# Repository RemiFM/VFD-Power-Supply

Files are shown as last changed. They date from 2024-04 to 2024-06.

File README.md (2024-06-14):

# VFD Power Supply
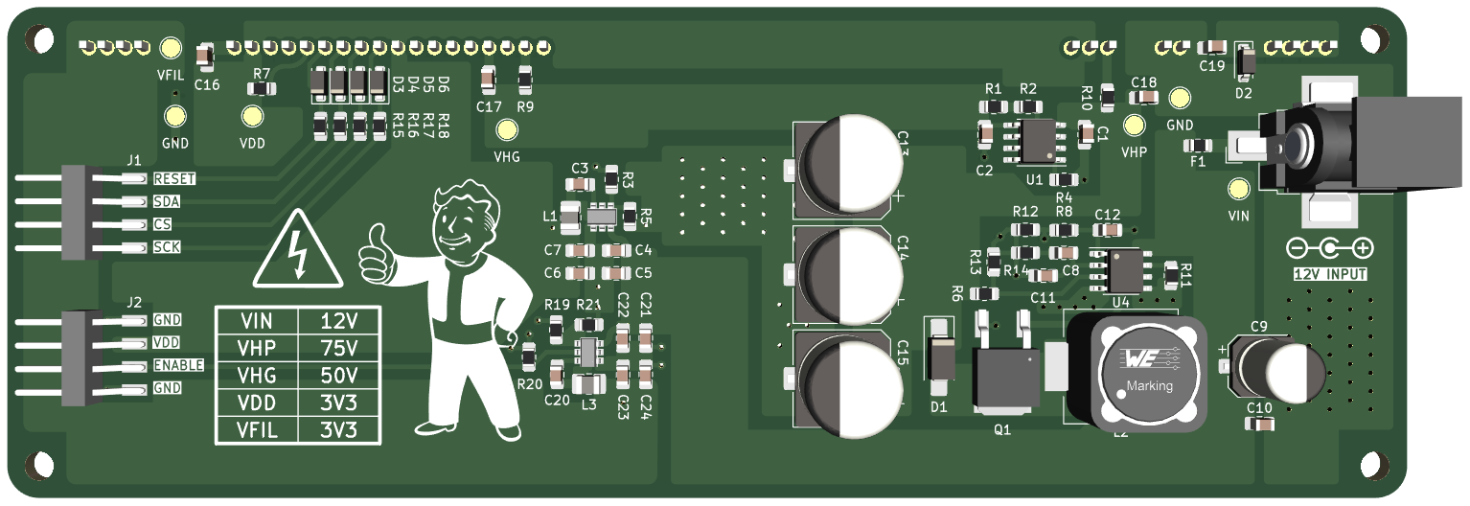
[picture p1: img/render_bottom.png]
Render Bottom


Power supply for the GP1294AI & GP1278BI (also marketed as VFD25648) vacuum fluorescent display. The supply requires a 12V input source, and outputs the necessary voltages to drive the anodes and filaments of the display. 

> [!CAUTION]
> The power supply outputs **voltages up to 75V** DC which can be hazardous. Handle with care.

## Usage
The VFD Display can be soldered to the front of the PCB. All components of the power supply are surface-mount technology (SMT) and are placed on the backside of the PCB. Only connect the display to the PCB after verifying all voltages on the power supply using the provided measuring points. The display can be controlled using any microcontroller that uses 3V3 logic (ESP32, Raspberry Pi...) using the general purpose 2.54mm male headers on the board.

## Ordering PCB
The production files necessary for manufacturing are bundled in the compressed folders [export/GP1294AI.zip](export/GP1294AI.zip) or [export/GP1278BI.zip](export/GP1278BI.zip), depending on the specific VFD display used. The gerber files are generated according to the guidelines of fabrication house JLCPCB. It is recommended to order the PCB from JLCPCB by uploading the compressed folder to their website, but other manufacturers (PCBWay, Eurocircuits...) should work as well.

## Ordering Components
A bill of materials (BOM) is available for download. The BOM contains Digi-Key part numbers, and is formatted in a way that can be uploaded to the Digi-Key website for effortless ordering.
Alternatively, the URL below leads to a public product list on Digi-Key which can be used for ordering the parts. As of June 2024, the total component cost is ~€23.

> [!TIP]
> Order all necessary components by following [this link](https://www.digikey.be/nl/mylists/list/VK1I6PIG8G). 

## Assembly
For assembly, please make use of the provided [schematic](schematic.pdf), available in pdf format.

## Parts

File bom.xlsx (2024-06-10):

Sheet: BOM
Group | Item | Designator | DigiKey | Cost | Number | Total | Remarks
Supply Voltage | Capacitor 10uF | C4 | 1276-1096-1-ND | €0.09 | 1 | €0.09 | footprint 0805
 | Capacitor 100nF | C5, C3 | 1276-6840-1-ND | €0.09 | 2 | €0.18 | footprint 0805
 | Capacitor 22uF | C6, C7 | 1276-6526-1-ND | €0.30 | 2 | €0.60 | footprint 0805
 | Resistor 31k6 | R3 | 311-31.6KCRCT-ND | €0.09 | 1 | €0.09 | footprint 0805
 | Resistor 10k | R5 | 311-10.0KCRCT-ND | €0.09 | 1 | €0.09 | footprint 0805
 | Inductor 2.2uH | L1 | 732-9690-1-ND | €0.49 | 1 | €0.49 | footprint 1008
 | Regulator AP62250 | U2 | 31-AP62250WU-7CT-ND | €0.30 | 1 | €0.30 | TSOT-26
Filament Driver | Capacitor 10uF | C21 | 1276-1096-1-ND | €0.09 | 1 | €0.09 | footprint 0805
 | Capacitor 100nF | C22, C20 | 1276-6840-1-ND | €0.09 | 2 | €0.18 | footprint 0805
 | Capacitor 22uF | C23, C24 | 1276-6526-1-ND | €0.30 | 2 | €0.60 | footprint 0805
 | Resistor 31k6 | R19 | 311-31.6KCRCT-ND | €0.09 | 1 | €0.09 | footprint 0805
 | Resistor 10k | R21, R20 | 311-10.0KCRCT-ND | €0.09 | 2 | €0.18 | footprint 0805
 | Inductor 2.2uH | L3 | 732-9690-1-ND | €0.49 | 1 | €0.49 | footprint 1008
 | Regulator AP62250 | U5 | 31-AP62250WU-7CT-ND | €0.30 | 1 | €0.30 | TSOT-26
Fused Input | Barrel Jack | J3 | CP-036AHPJCT-ND | €1.14 | 1 | €1.14
 | Barrel Plug | X | CP3-1000-ND | €1.13 | 1 | €1.13
 | 3A Fuse | F1 | MFU08053.00CT-ND | €0.56 | 1 | €0.56 | footprint 0805
Anode Driver | E-Capacitor 100uF | C9 | 732-8254-1-ND | €0.30 | 1 | €0.30
 | Capacitor 100nF | C10 | 1276-6840-1-ND | €0.09 | 1 | €0.09 | footprint 0805
 | Resistor 28k7 | R11 | 311-28.7KCRCT-ND | €0.09 | 1 | €0.09 | footprint 0805
 | Capacitor 39pF | C11 | 13-CC0805JRNPOBBN390CT-ND | €0.11 | 1 | €0.11 | HV, footprint 0805
 | Capacitor 330pF | C8 | 311-3287-1-ND | €0.13 | 1 | €0.13 | HV, footprint 0805
 | Capacitor 10pF | C12 | 311-4254-1-ND | €0.18 | 1 | €0.18 | HV, footprint 0805
 | Resistor 340k | R14 | 311-340KCRCT-ND | €0.09 | 1 | €0.09 | footprint 0805
 | Resistor 100R | R8 | 311-100CRCT-ND | €0.09 | 1 | €0.09 | footprint 0805
 | Resistor 0.1R | R12 | 311-0.1LUCT-ND | €0.39 | 1 | €0.39 | footprint 0805
 | Resistor 590k | R6 | 311-590KCRCT-ND | €0.09 | 1 | €0.09 | footprint 0805
 | Resistor 10k | R13 | 311-10.0KCRCT-ND | €0.09 | 1 | €0.09 | footprint 0805
 | Regulator LM3478 | U4 | 296-38111-1-ND | €2.41 | 1 | €2.41
 | Inductor 220uH | L2 | 732-1696-1-ND | €2.36 | 1 | €2.36
 | Diode SK220A | D1 | 1655-SK220ACT-ND | €0.41 | 1 | €0.41
 | Mosfet NCH | Q1 | 497-8774-1-ND | €2.69 | 1 | €2.69
 | E-Capacitor 47uF | C13, C14, C15 | 399-14797-1-ND | €0.68 | 3 | €2.04 | HV
Grid Driver | Capacitor 1uF | C1, C2 | 1276-1066-1-ND | €0.09 | 2 | €0.18 | footprint 0805
 | Resistor 220k | R4 | 311-220KARCT-ND | €0.09 | 1 | €0.09 | footprint 0806
 | Resistor 5K6 | R1 | 311-5.6KARCT-ND | €0.09 | 1 | €0.09 | footprint 0807
 | Resistor 56R | R2 | 311-56ARCT-ND | €0.09 | 1 | €0.09 | footprint 0808
 | Regulator | U1 | LR12LG-GCT-ND | €1.54 | 1 | €1.54
Connector | Male connector | J1, J2 | 952-3265-ND | €0.61 | 2 | €1.22
VFD Display | Resistor 200R | R15, R16, R17, R18 | 311-200CRCT-ND | €0.09 | 4 | €0.36
 | Resistor 100k | R7 | 311-100KCRCT-ND | €0.09 | 1 | €0.09
 | Resistor 10R | R9, R10 | 13-AC0805FR-7W10RLCT-ND | €0.09 | 2 | €0.18 | HV
 | Capacitor 100nF | C16, C19, C17, C18 | 1276-6840-1-ND | €0.09 | 4 | €0.36
 | Diode BZT52B3V3 | D3, D4, D5, D6 | BZT52B3V3RHGCT-ND | €0.19 | 4 | €0.76
 | Zener Diode | D2 | MMSZ5222BT1GOSCT-ND | €0.21 | 1 | €0.21
 |  |  |  |  |  | €23.33

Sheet: abridged
Item | Designator | DigiKey | Cost | Number | Total
Capacitor 10uF | C4 | 1276-1096-1-ND | 0.09 | 1 | 0.09
Capacitor 100nF | C5, C3 | 1276-6840-1-ND | 0.09 | 2 | 0.18
Capacitor 22uF | C6, C7 | 1276-6526-1-ND | 0.3 | 2 | 0.6
Resistor 31k6 | R3 | 311-31.6KCRCT-ND | 0.09 | 1 | 0.09
Resistor 10k | R5 | 311-10.0KCRCT-ND | 0.09 | 1 | 0.09
Inductor 2.2uH | L1 | 732-9690-1-ND | 0.49 | 1 | 0.49
Regulator AP62250 | U2 | 31-AP62250WU-7CT-ND | 0.3 | 1 | 0.3
Capacitor 10uF | C21 | 1276-1096-1-ND | 0.09 | 1 | 0.09
Capacitor 100nF | C22, C20 | 1276-6840-1-ND | 0.09 | 2 | 0.18
Capacitor 22uF | C23, C24 | 1276-6526-1-ND | 0.3 | 2 | 0.6
Resistor 31k6 | R19 | 311-31.6KCRCT-ND | 0.09 | 1 | 0.09
Resistor 10k | R21, R20 | 311-10.0KCRCT-ND | 0.09 | 2 | 0.18
Inductor 2.2uH | L3 | 732-9690-1-ND | 0.49 | 1 | 0.49
Regulator AP62250 | U5 | 31-AP62250WU-7CT-ND | 0.3 | 1 | 0.3
Barrel Jack | J3 | CP-036AHPJCT-ND | 1.14 | 1 | 1.14
Barrel Plug | X | CP3-1000-ND | 1.13 | 1 | 1.13
3A Fuse | F1 | MFU08053.00CT-ND | 0.56 | 1 | 0.56
E-Capacitor 100uF | C9 | 732-8254-1-ND | 0.3 | 1 | 0.3
Capacitor 100nF | C10 | 1276-6840-1-ND | 0.09 | 1 | 0.09
Resistor 28k7 | R11 | 311-28.7KCRCT-ND | 0.09 | 1 | 0.09
Capacitor 39pF | C11 | 13-CC0805JRNPOBBN390CT-ND | 0.11 | 1 | 0.11
Capacitor 330pF | C8 | 311-3287-1-ND | 0.13 | 1 | 0.13
Capacitor 10pF | C12 | 311-4254-1-ND | 0.18 | 1 | 0.18
Resistor 340k | R14 | 311-340KCRCT-ND | 0.09 | 1 | 0.09
Resistor 100R | R8 | 311-100CRCT-ND | 0.09 | 1 | 0.09
Resistor 0.1R | R12 | 311-0.1LUCT-ND | 0.39 | 1 | 0.39
Resistor 590k | R6 | 311-590KCRCT-ND | 0.09 | 1 | 0.09
Resistor 10k | R13 | 311-10.0KCRCT-ND | 0.09 | 1 | 0.09
Regulator LM3478 | U4 | 296-38111-1-ND | 2.41 | 1 | 2.41
Inductor 220uH | L2 | 732-1696-1-ND | 2.36 | 1 | 2.36
Diode SK220A | D1 | 1655-SK220ACT-ND | 0.41 | 1 | 0.41
Mosfet NCH | Q1 | 497-8774-1-ND | 2.69 | 1 | 2.69
E-Capacitor 47uF | C13, C14, C15 | 399-14797-1-ND | 0.68 | 3 | 2.04
Capacitor 1uF | C1, C2 | 1276-1066-1-ND | 0.09 | 2 | 0.18
Resistor 220k | R4 | 311-220KARCT-ND | 0.09 | 1 | 0.09
Resistor 5K6 | R1 | 311-5.6KARCT-ND | 0.09 | 1 | 0.09
Resistor 56R | R2 | 311-56ARCT-ND | 0.09 | 1 | 0.09
Regulator | U1 | LR12LG-GCT-ND | 1.54 | 1 | 1.54
Male connector | J1, J2 | 952-3265-ND | 0.61 | 2 | 1.22
Resistor 200R | R15, R16, R17, R18 | 311-200CRCT-ND | 0.09 | 4 | 0.36
Resistor 100k | R7 | 311-100KCRCT-ND | 0.09 | 1 | 0.09
Resistor 10R | R9, R10 | 13-AC0805FR-7W10RLCT-ND | 0.09 | 2 | 0.18
Capacitor 100nF | C16, C19, C17, C18 | 1276-6840-1-ND | 0.09 | 4 | 0.36
Diode BZT52B3V3 | D3, D4, D5, D6 | BZT52B3V3RHGCT-ND | 0.19 | 4 | 0.76
Zener Diode | D2 | MMSZ5222BT1GOSCT-ND | 0.21 | 1 | 0.21

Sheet: obsolete
Item | Designator | Digikey | Cost | Quantity | Total
Capacitor 10uF | C26, C14 |  |  | 2 | €0.00
Capacitor 100n | C13, C28, C3, C24, C27 |  |  | 5 | €0.00
Capacitor 1uF | C12 |  |  | 1 | €0.00
Resistor 10k | R11 |  |  | 1 | €0.00
Resistor 100k | R10, R17 |  |  | 2 | €0.00
Inductor 2.2uH | L2 | SRR1260-2R2YCT-ND | €1.09 | 1 | €1.09
Capacitor 15pF | C29 |  |  | 1 | €0.00
Resistor 22k1 | R25 |  |  | 1 | €0.00
Resistor 73k2 | R12 |  |  | 1 | €0.00
Capacitor 47uF | C30 |  |  | 1 | €0.00
Regulator IC | U6 | 296-40815-1-ND | €1.82 | 1 | €1.82
Capacitor 100 uF | C4 | 732-8254-1-ND | €0.30 | 1 | €0.30
Resistor 28k7 | R2 |  |  |  | €0.00
Capacitor 39pF | C1 |  |  |  | €0.00
Resistor 340k | R1 |  |  |  | €0.00
Capacitor 330 pF | C2 |  |  |  | €0.00
Regulator IC | U1 | 296-38111-1-ND | €2.41 | 1 | €2.41
Inductor 220uH | L1 | 732-1696-1-ND | €2.37 | 1 | €2.37
Mosfet NCH | Q1 | 497-8774-1-ND | €2.69 | 1 | €2.69
Capacitor HV? 10 pF | C5 |  |  |  | €0.00
Resistor HV 100R | R3 |  |  |  | €0.00
Resistor HV 100m | R4 |  |  |  | €0.00
Schottky diode | D1 | 1655-SK220ACT-ND | €0.41 | 1 | €0.41
Capacitor 47uF | C6, C7, C11 | 732-865060857005CT-ND | €1.02 | 3 | €3.06
Resistor 590k HV | R5 |  |  |  | €0.00
Resistor 10k HV | R6 |  |  |  | €0.00
Resistor 68R | R13 |  |  |  | €0.00
SSR IC | U3 | 264-TLP170AM(TPLECT-ND | €1.18 | 1 | €1.18
Barrel jack | J4 | CP-036AHPJCT-ND | €1.14 | 1 | €1.14
Fuse 3A | F1 | MFU08053.00CT-ND | €0.46 | 1 | €0.46
Connector | J1, J2 | 455-S4B-PH-SM4-TBCT-ND | €0.72 | 2 | €1.44
Capacitor 1uF HV | C9, C10 |  |  | 2 | €0.00
Regulator IC | U2 | LR12LG-GCT-ND | €1.54 | 1 | €1.54
Resistor 220k HV | R7 |  |  | 1 | €0.00
Resistor 56R HV | R9 |  |  | 1 | €0.00
Resistor 5K6 HV | R8 |  |  | 1 | €0.00
Resistor 200R | R21 X 4 |  |  | 4 | €0.00
Zener diode | D4, D5, D6, D7 | BZT52B3V3RHGCT-ND | €0.19 | 4 | €0.76
Resistor 10R HV | R19, R20 |  |  | 2 | €0.00
Capacitor 100nF HV | C25, C8 |  |  | 2 | €0.00
Zener diode | D8 | MMSZ5222BT1GOSCT-ND | €0.21 | 1 | €0.21
 |  |  |  |  | €20.88

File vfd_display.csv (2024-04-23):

Source: | C:\Users\remi.decoster\OneDrive - Flanders Make vzw\Documents\GitHub\PCBs\VFD Display\vfd_display\vfd_display.kicad_sch
Date: | 22/04/2024 00:50:16
Tool: | Eeschema 7.0.7
Generator: | C:\Program Files\KiCad\6.0\bin\scripting\plugins/bom_csv_grouped_by_value.py
Component Count: | 60
Individual Components:
Item | Qty | Reference(s) | Value | LibPart | Footprint | Datasheet | Digi-Key | DigiKey
 |  | C1 | 39pF | Device:C | Capacitor_SMD:C_0805_2012Metric_Pad1.18x1.45mm_HandSolder | ~
 |  | C2 | 330pF | Device:C | Capacitor_SMD:C_0805_2012Metric_Pad1.18x1.45mm_HandSolder | ~
 |  | C3 | 100nF | Device:C | Capacitor_SMD:C_0805_2012Metric_Pad1.18x1.45mm_HandSolder | ~
 |  | C4 | 100uF | Device:C_Polarized_US | Capacitor_SMD:CP_Elec_6.3x7.7 | ~ | 732-8254-1-ND
 |  | C5 | 10pF | Device:C | Capacitor_SMD:C_0805_2012Metric_Pad1.18x1.45mm_HandSolder | ~
 |  | C6 | 47uF | Device:C_Polarized_US | Capacitor_SMD:CP_Elec_10x10.5 | ~ | 732-865060857005CT-ND
 |  | C7 | 47uF | Device:C_Polarized_US | Capacitor_SMD:CP_Elec_10x10.5 | ~ | 732-865060857005CT-ND
 |  | C8 | 100nF | Device:C | Capacitor_SMD:C_0805_2012Metric_Pad1.18x1.45mm_HandSolder | ~
 |  | C9 | 1uF | Device:C | Capacitor_SMD:C_0805_2012Metric_Pad1.18x1.45mm_HandSolder | ~
 |  | C10 | 1uF | Device:C | Capacitor_SMD:C_0805_2012Metric_Pad1.18x1.45mm_HandSolder | ~
 |  | C11 | 47uF | Device:C_Polarized_US | Capacitor_SMD:CP_Elec_10x10.5 | ~ | 732-865060857005CT-ND
 |  | C12 | 1uF | Device:C | Capacitor_SMD:C_0805_2012Metric_Pad1.18x1.45mm_HandSolder | ~
 |  | C13 | 100nF | Device:C | Capacitor_SMD:C_0805_2012Metric_Pad1.18x1.45mm_HandSolder | ~
 |  | C14 | 10uF | Device:C | Capacitor_SMD:C_0805_2012Metric_Pad1.18x1.45mm_HandSolder | ~
 |  | C24 | 100nF | Device:C | Capacitor_SMD:C_0805_2012Metric_Pad1.18x1.45mm_HandSolder | ~
 |  | C25 | 100nF | Device:C | Capacitor_SMD:C_0805_2012Metric_Pad1.18x1.45mm_HandSolder | ~
 |  | C26 | 10uF | Device:C | Capacitor_SMD:C_0805_2012Metric_Pad1.18x1.45mm_HandSolder | ~
 |  | C27 | 100nF | Device:C | Capacitor_SMD:C_0805_2012Metric_Pad1.18x1.45mm_HandSolder | ~
 |  | C28 | 100nF | Device:C | Capacitor_SMD:C_0805_2012Metric_Pad1.18x1.45mm_HandSolder | ~
 |  | C29 | 15pF | Device:C | Capacitor_SMD:C_0805_2012Metric_Pad1.18x1.45mm_HandSolder | ~
 |  | C30 | 47uF | Device:C | Capacitor_SMD:C_0805_2012Metric_Pad1.18x1.45mm_HandSolder | ~
 |  | D1 | SK220A | Device:D_Schottky | Diode_SMD:D_SMA_Handsoldering | ~ | 1655-SK220ACT-ND
 |  | D4 | BZT52B3V3 | Device:D_Zener | Diode_SMD:D_SOD-123F | ~
 |  | D5 | BZT52B3V3 | Device:D_Zener | Diode_SMD:D_SOD-123F | ~
 |  | D6 | BZT52B3V3 | Device:D_Zener | Diode_SMD:D_SOD-123F | ~
 |  | D7 | BZT52B3V3 | Device:D_Zener | Diode_SMD:D_SOD-123F | ~
 |  | D8 | MMSZ5222BT1G | Device:D_Zener | Diode_SMD:D_SOD-123 | ~ | MMSZ5222BT1GOSCT-ND
 |  | F1 | MFU0805FF03000P100 | Device:Fuse | Fuse:Fuse_0805_2012Metric_Pad1.15x1.40mm_HandSolder | ~
 |  | J1 | Conn_01x04 | Connector_Generic:Conn_01x04 | Connector_JST:JST_PH_S4B-PH-SM4-TB_1x04-1MP_P2.00mm_Horizontal | ~ | 455-S4B-PH-SM4-TBCT-ND
 |  | J2 | Conn_01x04 | Connector_Generic:Conn_01x04 | Connector_JST:JST_PH_S4B-PH-SM4-TB_1x04-1MP_P2.00mm_Horizontal | ~ | 455-S4B-PH-SM4-TBCT-ND
 |  | J4 | PJ-036AH-SMT-TR | Connector:Barrel_Jack_Switch | Connector_BarrelJack:BarrelJack_CUI_PJ-036AH-SMT_Horizontal | ~
 |  | L1 | 220uH | Device:L | Inductor_SMD:L_Wuerth_WE-PD-Typ-LS_Handsoldering | ~ |  | 732-1696-1-ND
 |  | L2 | 2.2uH | Device:L | Inductor_SMD:L_Bourns_SRR1260 | ~ |  | SRR1260-2R2YCT-ND
 |  | Q1 | STD16N65M5 | Device:Q_NMOS_GDS | Remi_Footprints:STD16N65M5 | ~ | ?
 |  | R1 | 340k | Device:R_US | Resistor_SMD:R_0805_2012Metric_Pad1.20x1.40mm_HandSolder | ~
 |  | R2 | 28k7 | Device:R_US | Resistor_SMD:R_0805_2012Metric_Pad1.20x1.40mm_HandSolder | ~
 |  | R3 | 100R | Device:R_US | Resistor_SMD:R_0805_2012Metric_Pad1.20x1.40mm_HandSolder | ~
 |  | R4 | 100m | Device:R_US | Resistor_SMD:R_0805_2012Metric_Pad1.20x1.40mm_HandSolder | ~
 |  | R5 | 590k | Device:R_US | Resistor_SMD:R_0805_2012Metric_Pad1.20x1.40mm_HandSolder | ~
 |  | R6 | 10k | Device:R_US | Resistor_SMD:R_0805_2012Metric_Pad1.20x1.40mm_HandSolder | ~
 |  | R7 | 220k | Device:R_US | Resistor_SMD:R_0805_2012Metric_Pad1.20x1.40mm_HandSolder | ~
 |  | R8 | 5K6 | Device:R_US | Resistor_SMD:R_0805_2012Metric_Pad1.20x1.40mm_HandSolder | ~
 |  | R9 | 56R | Device:R_US | Resistor_SMD:R_0805_2012Metric_Pad1.20x1.40mm_HandSolder | ~
 |  | R10 | 100k | Device:R_US | Resistor_SMD:R_0805_2012Metric_Pad1.20x1.40mm_HandSolder | ~
 |  | R11 | 10k | Device:R_US | Resistor_SMD:R_0805_2012Metric_Pad1.20x1.40mm_HandSolder | ~
 |  | R12 | 73k2 | Device:R_US | Resistor_SMD:R_0805_2012Metric_Pad1.20x1.40mm_HandSolder | ~
 |  | R13 | 68R | Device:R_US | Resistor_SMD:R_0805_2012Metric_Pad1.20x1.40mm_HandSolder | ~
 |  | R17 | 100k | Device:R_US | Resistor_SMD:R_0805_2012Metric_Pad1.20x1.40mm_HandSolder | ~
 |  | R19 | 10R | Device:R_US | Resistor_SMD:R_0805_2012Metric_Pad1.20x1.40mm_HandSolder | ~
 |  | R20 | 10R | Device:R_US | Resistor_SMD:R_0805_2012Metric_Pad1.20x1.40mm_HandSolder | ~
 |  | R21 | 4 X 200R | Device:R_US | Resistor_SMD:R_0805_2012Metric_Pad1.20x1.40mm_HandSolder | ~
 |  | R22 | 200R | Device:R_US | Resistor_SMD:R_0805_2012Metric_Pad1.20x1.40mm_HandSolder | ~
 |  | R23 | 200R | Device:R_US | Resistor_SMD:R_0805_2012Metric_Pad1.20x1.40mm_HandSolder | ~
 |  | R24 | 200R | Device:R_US | Resistor_SMD:R_0805_2012Metric_Pad1.20x1.40mm_HandSolder | ~
 |  | R25 | 22k1 | Device:R_US | Resistor_SMD:R_0805_2012Metric_Pad1.20x1.40mm_HandSolder | ~
 |  | U1 | LM3478 | Regulator_Controller:LM3478MA | Package_SO:SOIC-8_3.9x4.9mm_P1.27mm | https://www.ti.com/lit/gpn/lm3478 | 296-38111-1-ND
 |  | U2 | LR12LG-G | Remi_Symbols:LR12 | Package_SO:SOIC-8_3.9x4.9mm_P1.27mm |  | LR12LG-GCT-ND
 |  | U3 | TLP170AM | Remi_Symbols:TLP170AM | Remi_Footprints:Toshiba-11-4M1S |  | 264-TLP170AM(TPLECT-ND
 |  | U5 | GP1294AI | Remi_Symbols:GP1294AI | Remi_Footprints:VFD_GP1294AI
 |  | U6 | TPS56628 | Remi_Symbols:TPS56628 | Package_SO:SOIC-8_3.9x4.9mm_P1.27mm
Collated Components:
Item | Qty | Reference(s) | Value | LibPart | Footprint | Datasheet | Digi-Key | DigiKey
1 | 1 | C1 | 39pF | Device:C | Capacitor_SMD:C_0805_2012Metric_Pad1.18x1.45mm_HandSolder | ~
2 | 1 | C2 | 330pF | Device:C | Capacitor_SMD:C_0805_2012Metric_Pad1.18x1.45mm_HandSolder | ~
3 | 7 | C3, C8, C13, C24, C25, C27, C28 | 100nF | Device:C | Capacitor_SMD:C_0805_2012Metric_Pad1.18x1.45mm_HandSolder | ~
4 | 1 | C4 | 100uF | Device:C_Polarized_US | Capacitor_SMD:CP_Elec_6.3x7.7 | ~ | 732-8254-1-ND
5 | 1 | C5 | 10pF | Device:C | Capacitor_SMD:C_0805_2012Metric_Pad1.18x1.45mm_HandSolder | ~
6 | 3 | C6, C7, C11 | 47uF | Device:C_Polarized_US | Capacitor_SMD:CP_Elec_10x10.5 | ~ | 732-865060857005CT-ND
7 | 3 | C9, C10, C12 | 1uF | Device:C | Capacitor_SMD:C_0805_2012Metric_Pad1.18x1.45mm_HandSolder | ~
8 | 2 | C14, C26 | 10uF | Device:C | Capacitor_SMD:C_0805_2012Metric_Pad1.18x1.45mm_HandSolder | ~
9 | 1 | C29 | 15pF | Device:C | Capacitor_SMD:C_0805_2012Metric_Pad1.18x1.45mm_HandSolder | ~
10 | 1 | C30 | 47uF | Device:C | Capacitor_SMD:C_0805_2012Metric_Pad1.18x1.45mm_HandSolder | ~
11 | 1 | D1 | SK220A | Device:D_Schottky | Diode_SMD:D_SMA_Handsoldering | ~ | 1655-SK220ACT-ND
12 | 4 | D4, D5, D6, D7 | BZT52B3V3 | Device:D_Zener | Diode_SMD:D_SOD-123F | ~
13 | 1 | D8 | MMSZ5222BT1G | Device:D_Zener | Diode_SMD:D_SOD-123 | ~ | MMSZ5222BT1GOSCT-ND
14 | 1 | F1 | MFU0805FF03000P100 | Device:Fuse | Fuse:Fuse_0805_2012Metric_Pad1.15x1.40mm_HandSolder | ~
15 | 2 | J1, J2 | Conn_01x04 | Connector_Generic:Conn_01x04 | Connector_JST:JST_PH_S4B-PH-SM4-TB_1x04-1MP_P2.00mm_Horizontal | ~ | 455-S4B-PH-SM4-TBCT-ND
16 | 1 | J4 | PJ-036AH-SMT-TR | Connector:Barrel_Jack_Switch | Connector_BarrelJack:BarrelJack_CUI_PJ-036AH-SMT_Horizontal | ~
17 | 1 | L1 | 220uH | Device:L | Inductor_SMD:L_Wuerth_WE-PD-Typ-LS_Handsoldering | ~ |  | 732-1696-1-ND
18 | 1 | L2 | 2.2uH | Device:L | Inductor_SMD:L_Bourns_SRR1260 | ~ |  | SRR1260-2R2YCT-ND
19 | 1 | Q1 | STD16N65M5 | Device:Q_NMOS_GDS | Remi_Footprints:STD16N65M5 | ~ | ?
20 | 1 | R1 | 340k | Device:R_US | Resistor_SMD:R_0805_2012Metric_Pad1.20x1.40mm_HandSolder | ~
21 | 1 | R2 | 28k7 | Device:R_US | Resistor_SMD:R_0805_2012Metric_Pad1.20x1.40mm_HandSolder | ~
22 | 1 | R3 | 100R | Device:R_US | Resistor_SMD:R_0805_2012Metric_Pad1.20x1.40mm_HandSolder | ~
23 | 1 | R4 | 100m | Device:R_US | Resistor_SMD:R_0805_2012Metric_Pad1.20x1.40mm_HandSolder | ~
24 | 1 | R5 | 590k | Device:R_US | Resistor_SMD:R_0805_2012Metric_Pad1.20x1.40mm_HandSolder | ~
25 | 2 | R6, R11 | 10k | Device:R_US | Resistor_SMD:R_0805_2012Metric_Pad1.20x1.40mm_HandSolder | ~
26 | 1 | R7 | 220k | Device:R_US | Resistor_SMD:R_0805_2012Metric_Pad1.20x1.40mm_HandSolder | ~
27 | 1 | R8 | 5K6 | Device:R_US | Resistor_SMD:R_0805_2012Metric_Pad1.20x1.40mm_HandSolder | ~
28 | 1 | R9 | 56R | Device:R_US | Resistor_SMD:R_0805_2012Metric_Pad1.20x1.40mm_HandSolder | ~
29 | 2 | R10, R17 | 100k | Device:R_US | Resistor_SMD:R_0805_2012Metric_Pad1.20x1.40mm_HandSolder | ~
30 | 1 | R12 | 73k2 | Device:R_US | Resistor_SMD:R_0805_2012Metric_Pad1.20x1.40mm_HandSolder | ~
31 | 1 | R13 | 68R | Device:R_US | Resistor_SMD:R_0805_2012Metric_Pad1.20x1.40mm_HandSolder | ~
32 | 2 | R19, R20 | 10R | Device:R_US | Resistor_SMD:R_0805_2012Metric_Pad1.20x1.40mm_HandSolder | ~
33 | 1 | R21 | 4 X 200R | Device:R_US | Resistor_SMD:R_0805_2012Metric_Pad1.20x1.40mm_HandSolder | ~
34 | 3 | R22, R23, R24 | 200R | Device:R_US | Resistor_SMD:R_0805_2012Metric_Pad1.20x1.40mm_HandSolder | ~
35 | 1 | R25 | 22k1 | Device:R_US | Resistor_SMD:R_0805_2012Metric_Pad1.20x1.40mm_HandSolder | ~
36 | 1 | U1 | LM3478 | Regulator_Controller:LM3478MA | Package_SO:SOIC-8_3.9x4.9mm_P1.27mm | https://www.ti.com/lit/gpn/lm3478 | 296-38111-1-ND
37 | 1 | U2 | LR12LG-G | Remi_Symbols:LR12 | Package_SO:SOIC-8_3.9x4.9mm_P1.27mm |  | LR12LG-GCT-ND
38 | 1 | U3 | TLP170AM | Remi_Symbols:TLP170AM | Remi_Footprints:Toshiba-11-4M1S |  | 264-TLP170AM(TPLECT-ND
39 | 1 | U5 | GP1294AI | Remi_Symbols:GP1294AI | Remi_Footprints:VFD_GP1294AI
40 | 1 | U6 | TPS56628 | Remi_Symbols:TPS56628 | Package_SO:SOIC-8_3.9x4.9mm_P1.27mm

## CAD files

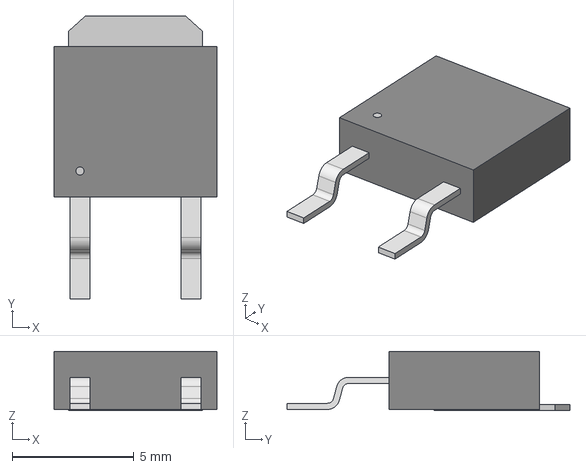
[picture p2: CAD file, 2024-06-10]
stp_models/DPAK_6N65M5_STM.step
6.71 x 11.6 x 2.44 mm

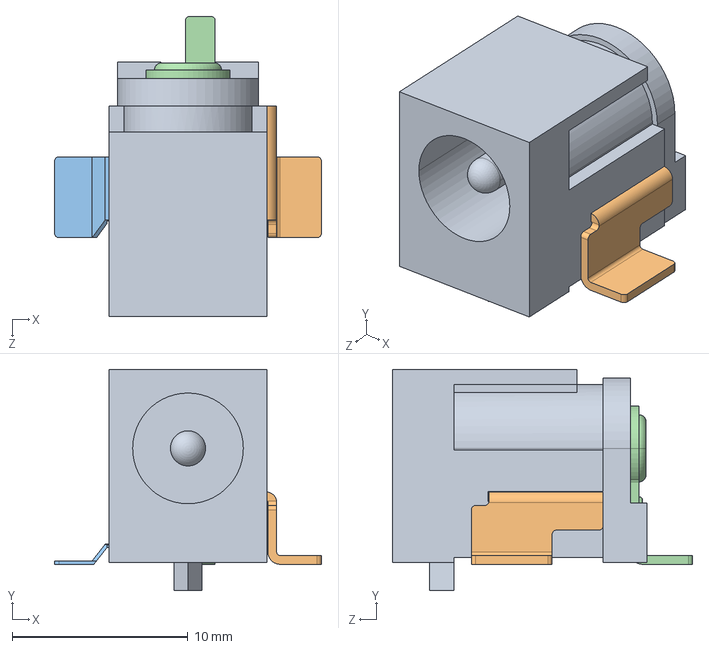
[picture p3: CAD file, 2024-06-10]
stp_models/CUI_DEVICES_PJ-036AH-SMT-TR.step
15.2 x 12.6 x 17.1 mm

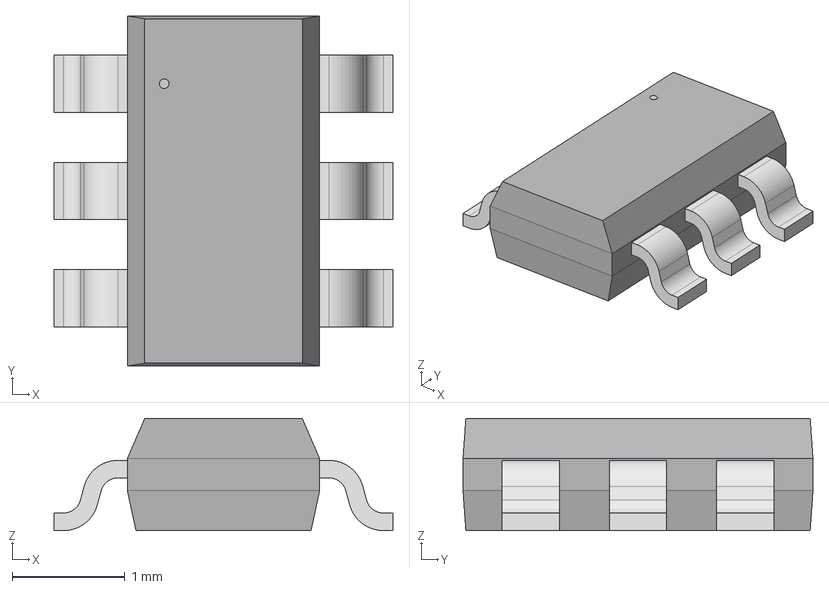
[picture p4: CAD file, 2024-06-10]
stp_models/TSOT26_STANDARD__DIO.step
3.00 x 3.10 x 0.993 mm

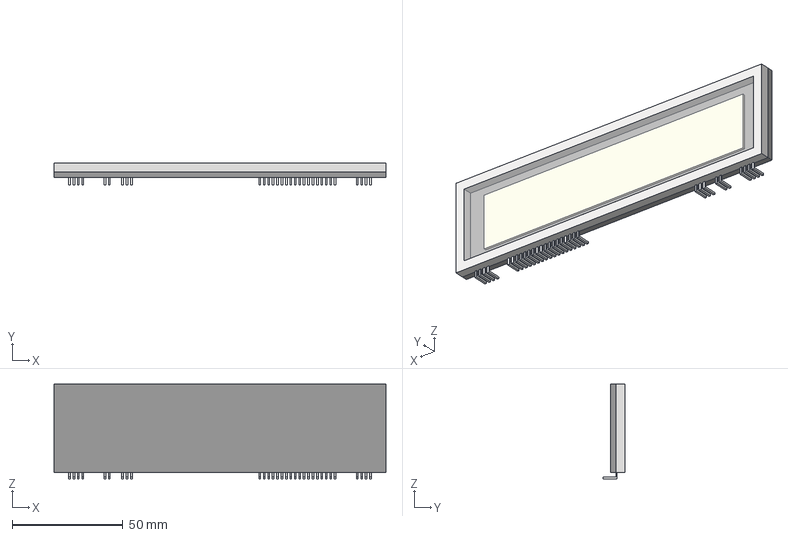
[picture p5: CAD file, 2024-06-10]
stp_models/VFD_display.stp
150.0 x 9.72 x 42.9 mm
VFD_bottom
VFD_middle
VFD_screen
VFD_glass

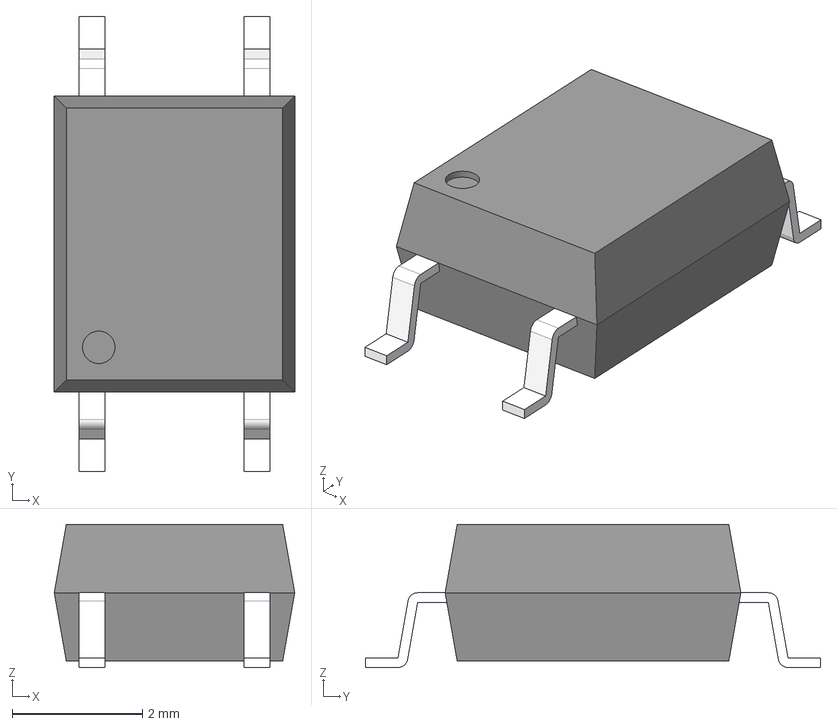
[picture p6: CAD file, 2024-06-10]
stp_models/4pin SO6.STEP
3.70 x 7.00 x 2.20 mm

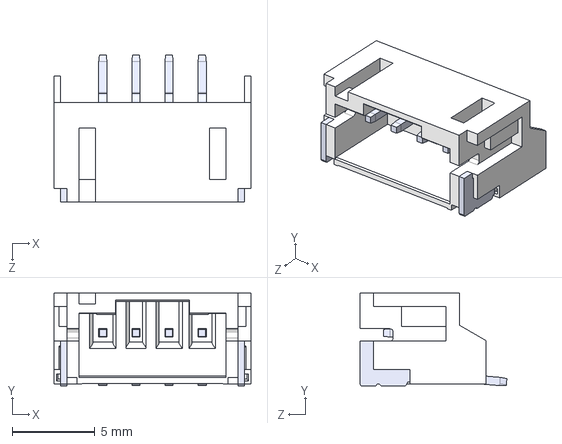
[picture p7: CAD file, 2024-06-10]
stp_models/S4B-PH-SM4-TB_LF__SN_.stp
11.9 x 5.60 x 8.87 mm

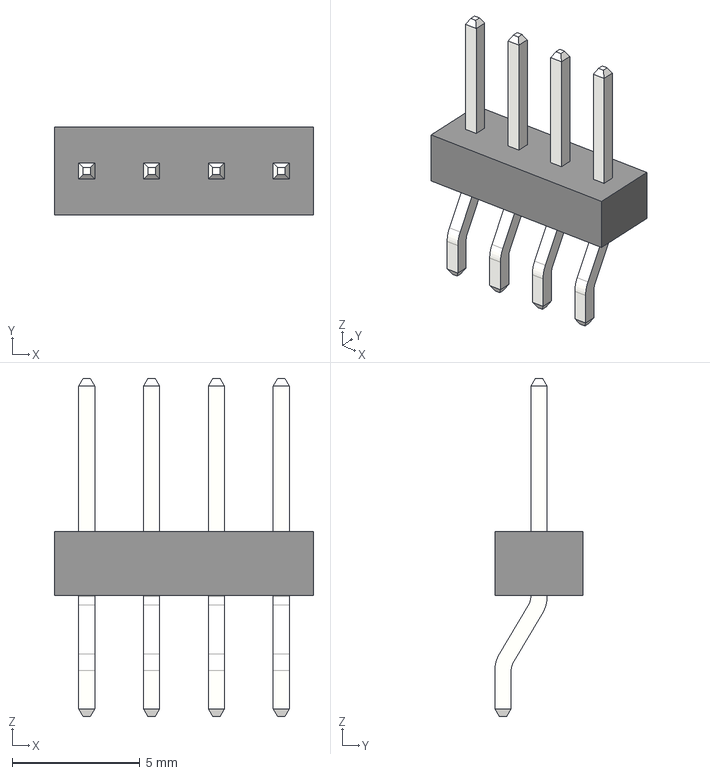
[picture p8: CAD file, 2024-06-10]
stp_models/M20-89004XX_asm.stp
10.2 x 3.46 x 13.2 mm
M20-890_MOULD
M20-890_PIN x 4

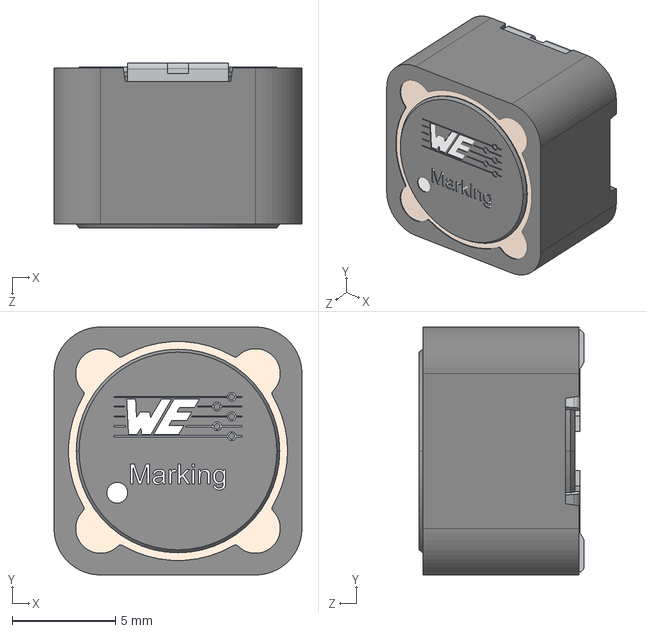
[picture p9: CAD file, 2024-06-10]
stp_models/7447709221.stp
12.0 x 12.0 x 8.00 mm

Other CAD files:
stp_models/M20-8900405.stp
stp_models/CUI_DEVICES_PJ-036AH-SMT-TR.stp
stp_models/M20-8900405.stl

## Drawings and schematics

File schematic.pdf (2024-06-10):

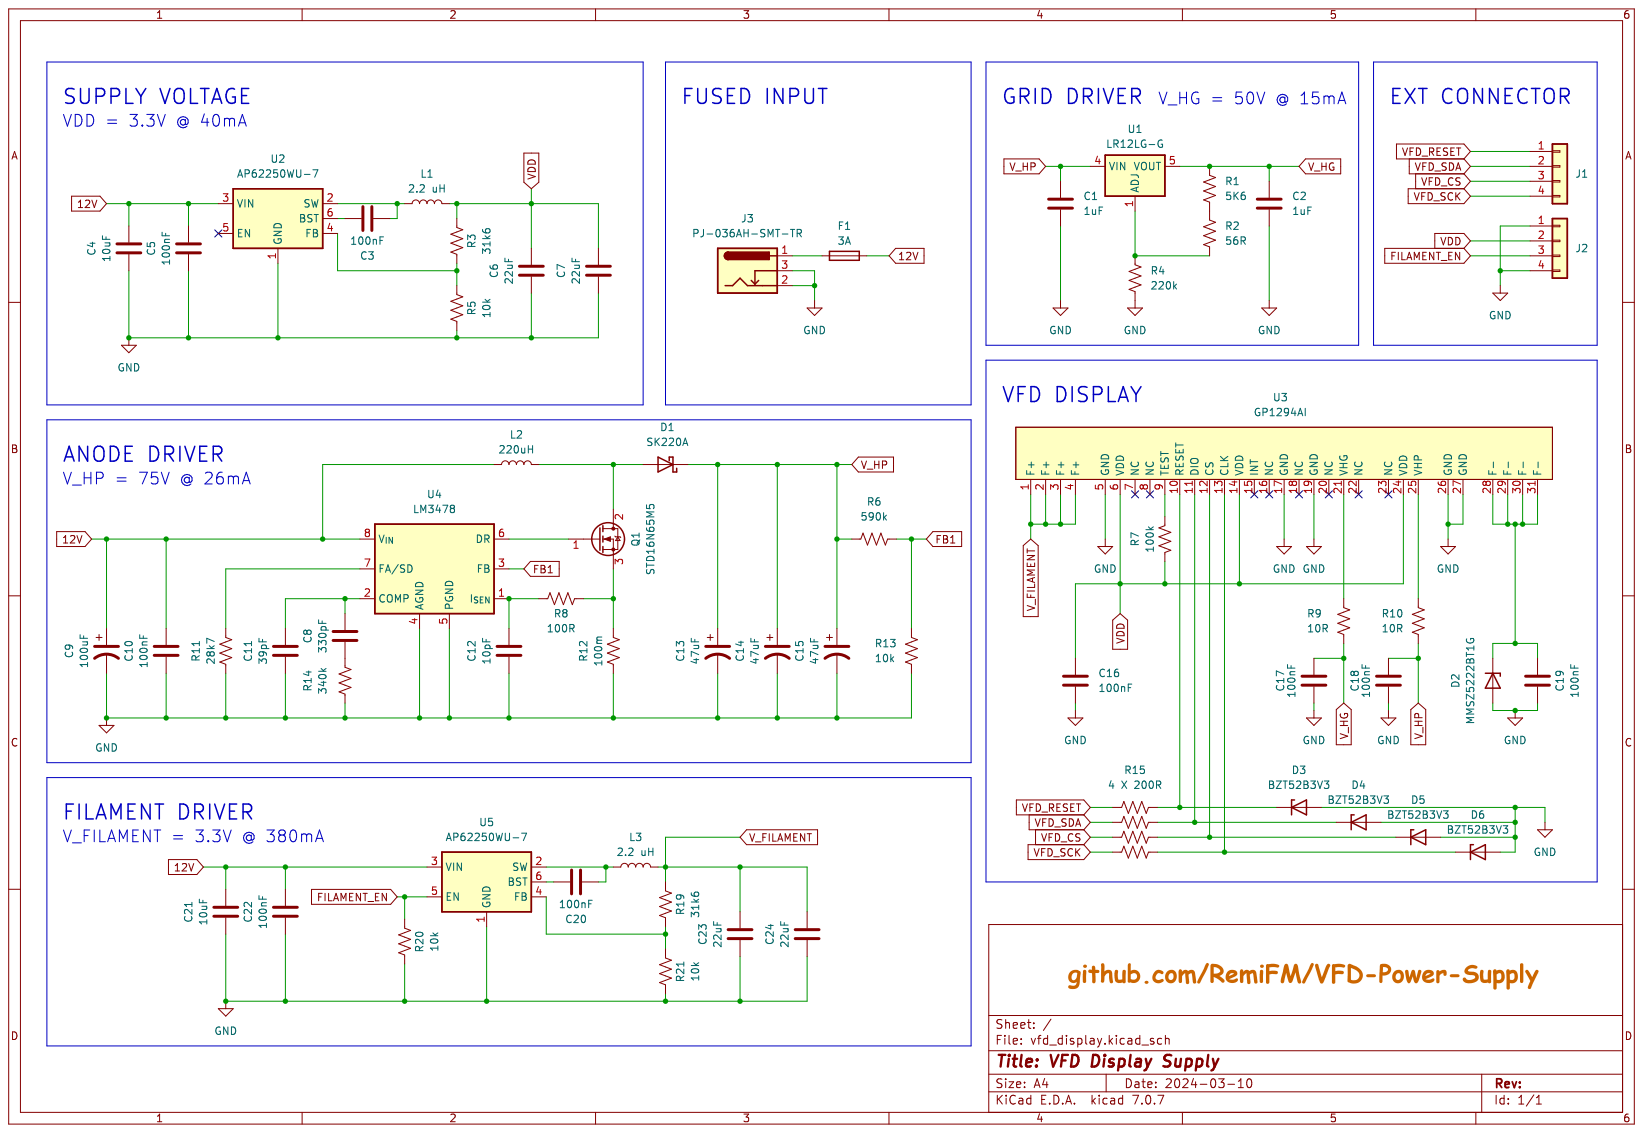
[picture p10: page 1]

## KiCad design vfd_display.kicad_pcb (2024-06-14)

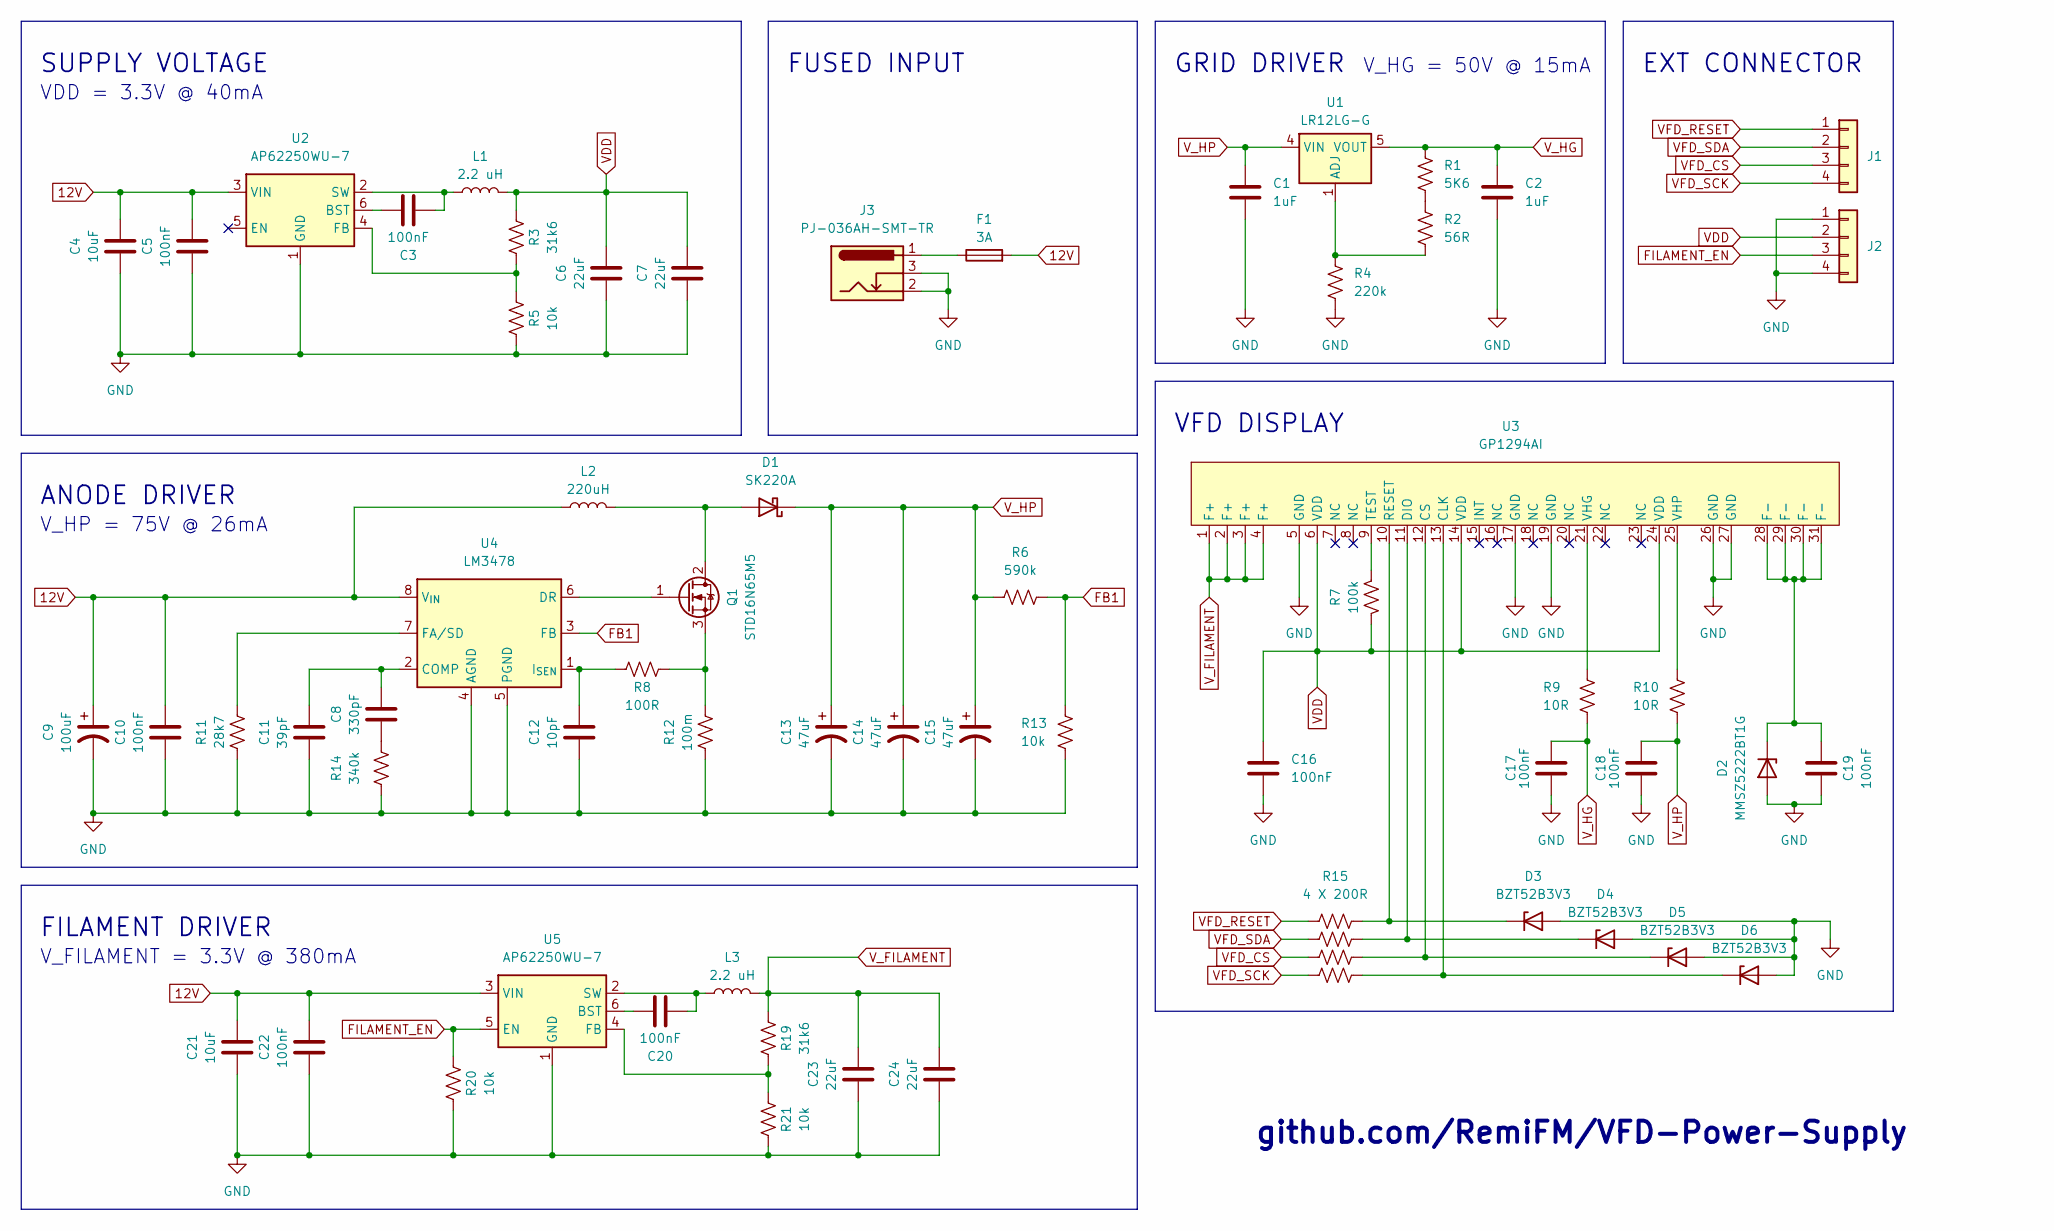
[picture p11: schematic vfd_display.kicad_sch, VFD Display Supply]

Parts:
C1, C2: 1uF; C_0805_2012Metric_Pad1.18x1.45mm_HandSolder
C3, C5, C10, C16, C17, C18, C19, C20, C22: 100nF; C_0805_2012Metric_Pad1.18x1.45mm_HandSolder
C4, C21: 10uF; C_0805_2012Metric_Pad1.18x1.45mm_HandSolder
C6, C7, C23, C24: 22uF; C_0805_2012Metric_Pad1.18x1.45mm_HandSolder
C8: 330pF; C_0805_2012Metric_Pad1.18x1.45mm_HandSolder
C9: 100uF; CP_Elec_6.3x7.7; Digi-Key 732-8254-1-ND
C11: 39pF; C_0805_2012Metric_Pad1.18x1.45mm_HandSolder
C12: 10pF; C_0805_2012Metric_Pad1.18x1.45mm_HandSolder
C13, C14, C15: 47uF; CP_Elec_10x10.5; Digi-Key 732-865060857005CT-ND
D1: SK220A; D_SMA_Handsoldering; Digi-Key 1655-SK220ACT-ND
D2: MMSZ5222BT1G; D_SOD-123; Digi-Key MMSZ5222BT1GOSCT-ND
D3, D4, D5, D6: BZT52B3V3; D_SOD-123F
F1: 3A; Fuse_0805_2012Metric_Pad1.15x1.40mm_HandSolder; DigiKeu MFU0805FF03000P100
J1: Conn_01x04; M20-8900405; Digi-Key 952-3265-ND
J2: Conn_01x04; M20-8900405; Digi-Key M20-8900405
J3: PJ-036AH-SMT-TR; BarrelJack_CUI_PJ-036AH-SMT_Horizontal
L1, L3: 2.2 uH; L_1008_2520Metric_Pad1.43x2.20mm_HandSolder; DigiKey 732-9690-1-ND
L2: 220uH; L_Wuerth_WE-PD-Typ-LS_Handsoldering; DigiKey 732-1696-1-ND
Q1: STD16N65M5; Digi-Key 497-8774-1-ND
R1: 5K6; R_0805_2012Metric_Pad1.20x1.40mm_HandSolder
R2: 56R; R_0805_2012Metric_Pad1.20x1.40mm_HandSolder
R3, R19: 31k6; R_0805_2012Metric_Pad1.20x1.40mm_HandSolder
R4: 220k; R_0805_2012Metric_Pad1.20x1.40mm_HandSolder
R5, R13, R20, R21: 10k; R_0805_2012Metric_Pad1.20x1.40mm_HandSolder
R6: 590k; R_0805_2012Metric_Pad1.20x1.40mm_HandSolder
R7: 100k; R_0805_2012Metric_Pad1.20x1.40mm_HandSolder
R8: 100R; R_0805_2012Metric_Pad1.20x1.40mm_HandSolder
R9, R10: 10R; R_0805_2012Metric_Pad1.20x1.40mm_HandSolder
R11: 28k7; R_0805_2012Metric_Pad1.20x1.40mm_HandSolder
R12: 100m; R_0805_2012Metric_Pad1.20x1.40mm_HandSolder
R14: 340k; R_0805_2012Metric_Pad1.20x1.40mm_HandSolder
R15: 4 X 200R; R_0805_2012Metric_Pad1.20x1.40mm_HandSolder
R16, R17, R18: 200R; R_0805_2012Metric_Pad1.20x1.40mm_HandSolder
U1: LR12LG-G; SOIC-8_3.9x4.9mm_P1.27mm; Digi-Key LR12LG-GCT-ND
U2, U5: AP62250WU-7; TSOT26
U3: GP1294AI; VFD_GP1294AI
U4: LM3478; SOIC-8_3.9x4.9mm_P1.27mm; Digi-Key 296-38111-1-ND

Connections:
12V: C4.1, C5.1, C9.1, C10.1, C21.1, C22.1, F1.2, L2.1, U2.3 (VIN), U4.8 (V_{IN}), U5.3 (VIN); also elsewhere on the board
FB1: R6.2, R13.1, U4.3 (FB)
FILAMENT_EN: J2.3, R20.2, U5.5 (EN)
GND: C1.2, C2.2, C4.2, C5.2, C6.2, C7.2, C9.2, C10.2, C11.2, C12.2, C13.2, C14.2, C15.2, C16.1, C17.2, C18.2, C19.2, C21.2, C22.2, C23.2, C24.2, D2.2 (A), D3.2 (A), D4.2 (A), D5.2 (A), D6.2 (A), J2.1, J2.4, J3.2, J3.3, R4.2, R5.1, R11.2, R12.2, R13.2, R14.2, R20.1, R21.1, U2.1 (GND), U3.5 (GND), U3.17 (GND), U3.19 (GND), U3.26 (GND), U3.27 (GND), U4.4 (AGND), U4.5 (PGND), U5.1 (GND); also elsewhere on the board
unnamed: C8.2, R14.1
unnamed: D1.2 (A), L2.2, Q1.2 (D)
unnamed: C19.1, D2.1 (K), U3.28 (F-), U3.29 (F-), U3.30 (F-), U3.31 (F-)
unnamed: D3.1 (K), R15.2, U3.10 (RESET)
unnamed: D4.1 (K), R16.2, U3.11 (DIO)
unnamed: D5.1 (K), R17.2, U3.12 (CS)
unnamed: D6.1 (K), R18.2, U3.13 (CLK)
unnamed: F1.1, J3.1
unnamed: Q1.1 (G), U4.6 (DR)
unnamed: Q1.3 (S), R8.2, R12.1
unnamed: R1.2, R2.1
unnamed: R2.2, R4.1, U1.1 (ADJ)
unnamed: C3.1, U2.6 (BST)
unnamed: R3.1, R5.2, U2.4 (FB)
unnamed: C3.2, L1.1, U2.2 (SW)
unnamed: R7.2, U3.9 (TEST)
unnamed: R9.1, U3.21 (VHG)
unnamed: R10.1, U3.25 (VHP)
unnamed: C8.1, C11.1, U4.2 (COMP)
unnamed: R11.1, U4.7 (FA/SD)
unnamed: C12.1, R8.1, U4.1 (I_{SEN})
unnamed: C20.1, U5.6 (BST)
unnamed: R19.1, R21.2, U5.4 (FB)
unnamed: C20.2, L3.1, U5.2 (SW)
VDD: C6.1, C7.1, C16.2, J2.2, L1.2, R3.2, R7.1, U3.6 (VDD), U3.14 (VDD), U3.24 (VDD); also elsewhere on the board
VFD_CS: J1.3, R17.1
VFD_RESET: J1.1, R15.1
VFD_SCK: J1.4, R18.1
VFD_SDA: J1.2, R16.1
V_FILAMENT: C23.1, C24.1, L3.2, R19.2, U3.1 (F+), U3.2 (F+), U3.3 (F+), U3.4 (F+); also elsewhere on the board
V_HG: C2.1, C17.1, R1.1, R9.2, U1.5 (VOUT); also elsewhere on the board
V_HP: C1.1, C13.1, C14.1, C15.1, C18.1, D1.1 (K), R6.1, R10.2, U1.4 (VIN); also elsewhere on the board

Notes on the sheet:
V_FILAMENT = 3.3V @ 380mA
SUPPLY VOLTAGE
VDD = 3.3V @ 40mA
FUSED INPUT
EXT CONNECTOR
V_HP = 75V @ 26mA
GRID DRIVER
FILAMENT DRIVER
github.com/RemiFM/VFD-Power-Supply
VFD DISPLAY
ANODE DRIVER
V_HG = 50V @ 15mA

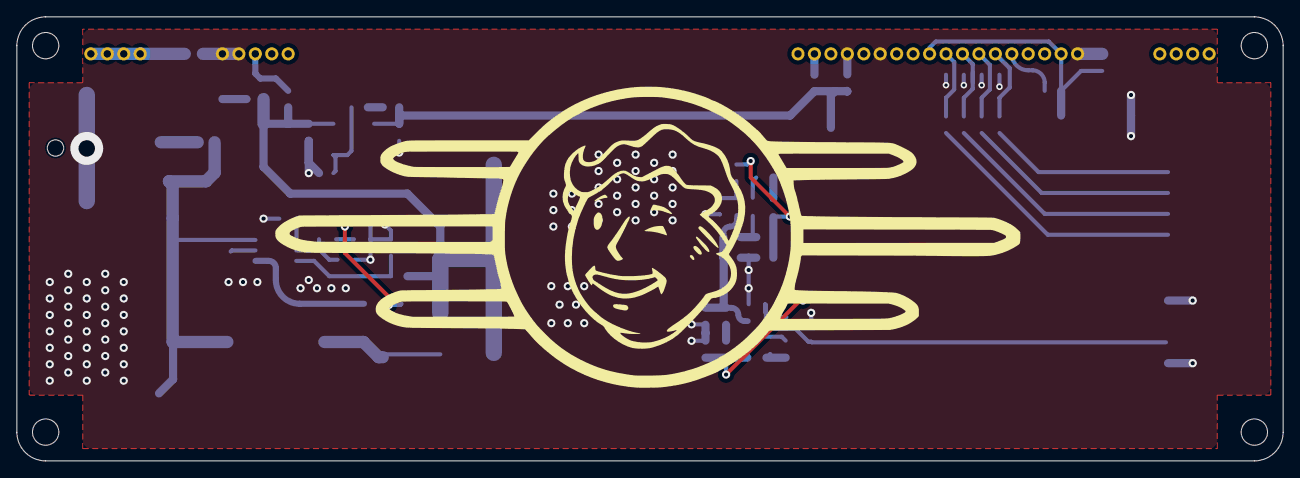
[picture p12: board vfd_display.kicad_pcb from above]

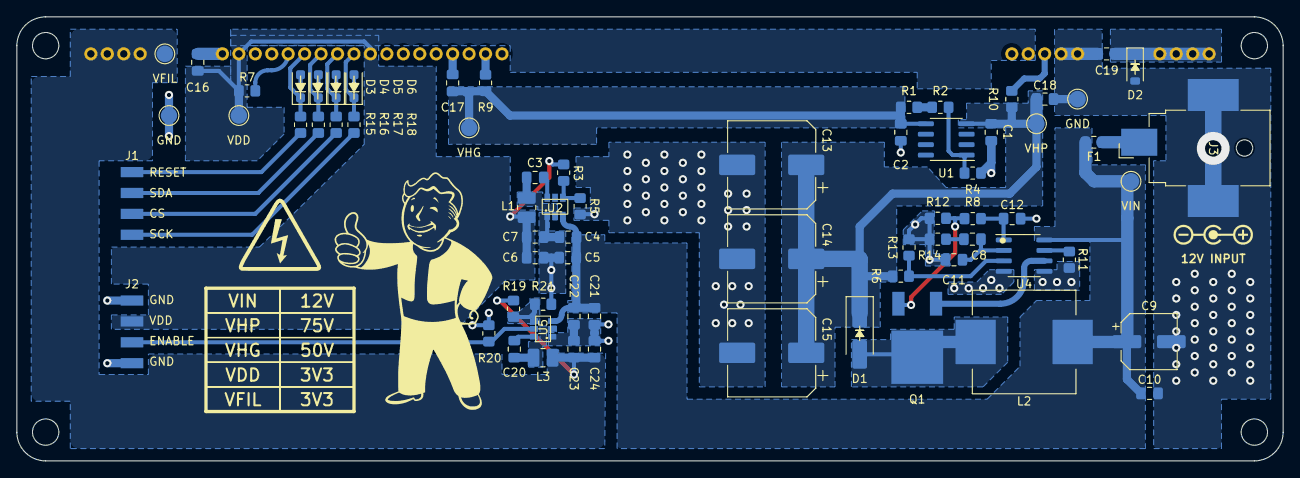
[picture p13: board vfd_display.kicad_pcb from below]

Board: 2 copper layers, 154.0 x 54.0 mm, 71 parts (70 on the bottom side), 36 nets.

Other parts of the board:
GND: TestPoint_Pad_D2.0mm
GND#2: TestPoint_Pad_D2.0mm
VDD: TestPoint_Pad_D2.0mm
VFIL: TestPoint_Pad_D2.0mm
VHG: TestPoint_Pad_D2.0mm
VHP: TestPoint_Pad_D2.0mm
VIN: TestPoint_Pad_D2.0mm

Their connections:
12V: VIN.1; also elsewhere on the board
GND: GND.1, GND#2.1; also elsewhere on the board
VDD: VDD.1; also elsewhere on the board
V_FILAMENT: VFIL.1; also elsewhere on the board
V_HG: VHG.1; also elsewhere on the board
V_HP: VHP.1; also elsewhere on the board

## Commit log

2024-06-10 BOM Update
    [bom.xlsx, vfd_display.csv, vfd_display.kicad_pcb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]
2024-06-10 3D Component Models
    [4pin SO6.STEP, 7447709221.stp, CUI_DEVICES_PJ-036AH-SMT-TR.step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]
2024-06-10 BOM Updates
    [bom.xlsx, bom_digikey.csv]
2024-06-10 Fabrication outputs
    [vfd_display-B_Cu.gbl, vfd_display-B_Cu.gbr, vfd_display-B_Mask.gbr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]
2024-06-12 Add teardrops
    [vfd_display-B_Cu.gbl, vfd_display-B_Mask.gbs, vfd_display-B_Paste.gbp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]
2024-06-14 Minor tweaks
    [vfd_display-B_Cu.gbl, vfd_display-B_Mask.gbs, vfd_display-B_Paste.gbp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]
2024-06-14 GP1278BI Variation
    [vfd_display-B_Cu.gbl, vfd_display-B_Mask.gbs, vfd_display-B_Paste.gbp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]
